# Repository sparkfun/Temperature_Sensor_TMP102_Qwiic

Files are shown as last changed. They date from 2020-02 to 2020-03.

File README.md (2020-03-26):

SparkFun Digital Temperature Sensor - TMP102 (Qwiic)
============================================

[SparkFun Digital Temperature Sensor - TMP102 (Qwiic)  
*SparkFun Digital Temperature Sensor - TMP102 (Qwiic) (SEN-16304)*](https://www.sparkfun.com/products/16304)

Qwiic enabled breakout board for TMP102 digital temperature sensor [The datasheet can be found here.](https://www.sparkfun.com/datasheets/Sensors/Temperature/tmp102.pdf)

Repository Contents
-------------------

* **/Documentation** - Datasheet for the TMP102 (.pdf)
* **/Hardware** - All Eagle design files (.brd and .sch)
* **/Production** - Production panel files

Documentation
--------------
* **[Library](https://github.com/sparkfun/SparkFun_TMP102_Arduino_Library)** - Arduino library for the SparkFun Digital Temperature Sensor - TMP102 (Qwiic).
* **[Hookup Guide](https://learn.sparkfun.com/tutorials/sparkfun-qwiic-digital-temperature-sensor---tmp102-hookup-guide)** - Basic hookup guide for the SparkFun Digital Temperature Sensor - TMP102 (Qwiic).
  
License Information
-------------------
The hardware is released under [Creative Commons Share-alike 3.0](http://creativecommons.org/licenses/by-sa/3.0/).  
All other code is open source so please feel free to do anything you want with it; you buy me a beer if you use this and we meet someday ([Beerware license](http://en.wikipedia.org/wiki/Beerware)).

Design by Kade Alexander Jensen - updated by Alex Wende

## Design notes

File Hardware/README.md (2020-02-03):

SparkFun Temperature Sensor TMP102 (Qwiic) Design Files
=====================================

The .sch and .brd files hare are Eagle CAD schematic and PCB design files from SparkFun Electronics.
A freeware version of Eagle can be found [here](http://www.cadsoftusa.com/download-eagle/freeware/).

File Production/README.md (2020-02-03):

SparkFun Temperature Sensor TMP102(Qwiic) Production Files
=========================================

These are the production files SparkFun uses for printing PCBs.

License Information
-------------------
This product is open source! 

The hardware is released under [Creative Commons ShareAlike 4.0 International](https://creativecommons.org/licenses/by-sa/4.0/).

Please use, reuse, and modify these files as you see fit. Please maintain attribution to SparkFun Electronics and release anything derivative under the same license.

Distributed as-is; no warranty is given.

- Your friends at SparkFun.

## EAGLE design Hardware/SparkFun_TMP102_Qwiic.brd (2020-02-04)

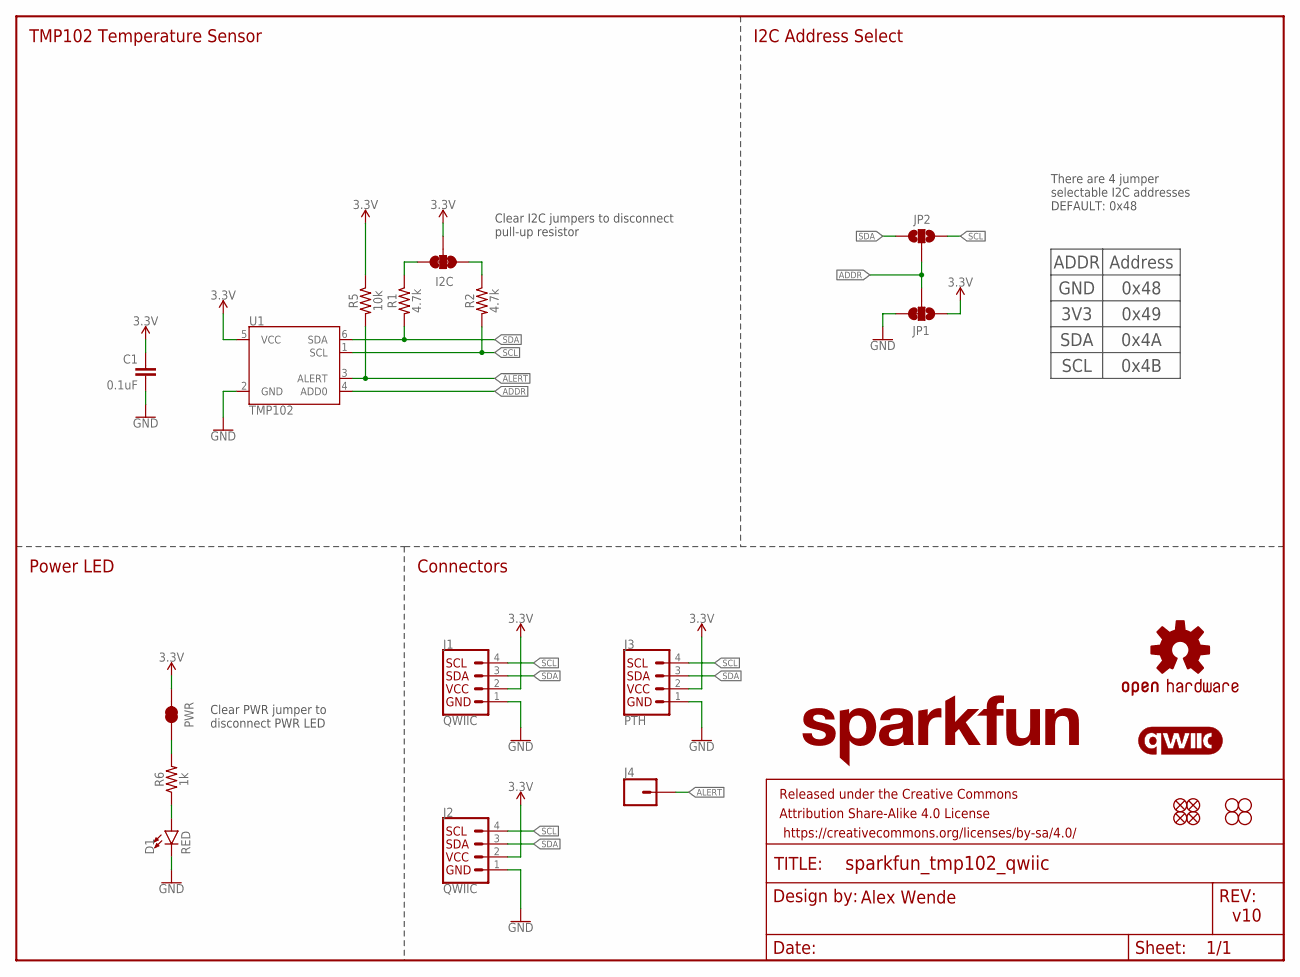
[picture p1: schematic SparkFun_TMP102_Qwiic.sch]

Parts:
C1: 0.1uF; 0603
D1: RED; LED-0603
FD1, FD2, FD3, FD4: FIDUCIALUFIDUCIAL; FIDUCIAL-MICRO
FRAME1: FRAME-LETTER; CREATIVE_COMMONS
H1, H2, H3, H4: STAND-OFF
J1, J2: QWIIC; JST04_1MM_RA
J3: PTH; 1X04_NO_SILK
J4: CONN_01PTH_NO_SILK_YES_STOP; 1X01_NO_SILK
JP1: JUMPER-SMT_3_1-NC_TRACE_NO-SILK; SMT-JUMPER_3_1-NC_TRACE_NO-SILK
JP2: JUMPER-SMT_3_NO_NO-SILK; SMT-JUMPER_3_NO_NO-SILK
JP3: I2C; SMT-JUMPER_3_2-NC_TRACE_SILK
JP4: PWR; SMT-JUMPER_2_NC_TRACE_SILK
LOGO1: SFE_LOGO_NAME.1_INCH; SFE_LOGO_NAME_.1
LOGO2: QWIIC_LOGO_5MM; QWIIC_5MM
LOGO3: OSHW-LOGOS; OSHW-LOGO-S
R1, R2: 4.7k; 0603
R5: 10k; 0603
R6: 1k; 0603
U1: TMP102; SOT563

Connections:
3.3V: C1.1, J1.2, J2.2, J3.2, JP1.1, JP3.2, JP4.2, R5.1, U1.5 (VCC)
!ALERT: J4.1, R5.2, U1.3 (ALERT)
ADDR: JP1.2, JP2.2, U1.4 (ADD0)
GND: C1.2, D1.C, J1.1, J2.1, J3.1, JP1.3, U1.2 (GND)
unnamed: JP3.3, R1.1
unnamed: JP3.1, R2.1
unnamed: D1.A, R6.1
unnamed: JP4.1, R6.2
SCL: J1.4, J2.4, J3.4, JP2.1, R2.2, U1.1 (SCL)
SDA: J1.3, J2.3, J3.3, JP2.3, R1.2, U1.6 (SDA)

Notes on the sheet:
v10
Address
0x48
0x49
0x4A
0x4B
GND
3V3
SDA
SCL
ADDR
I2C Address Select
TMP102 Temperature Sensor
Connectors
There are 4 jumper selectable I2C addresses DEFAULT: 0x48
Clear I2C jumpers to disconnect pull-up resistor
Clear PWR jumper to disconnect PWR LED
Power LED
Alex Wende

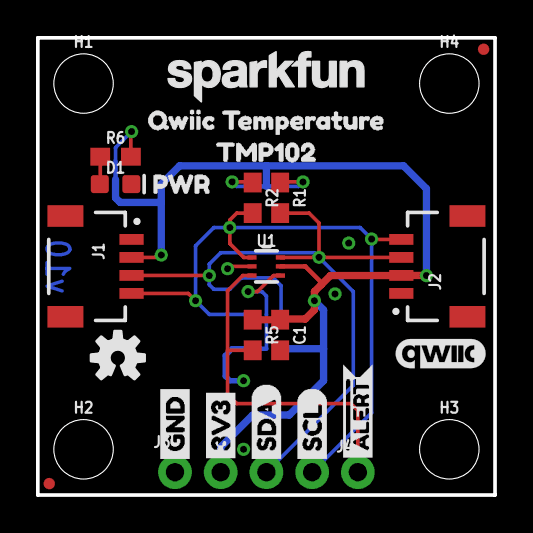
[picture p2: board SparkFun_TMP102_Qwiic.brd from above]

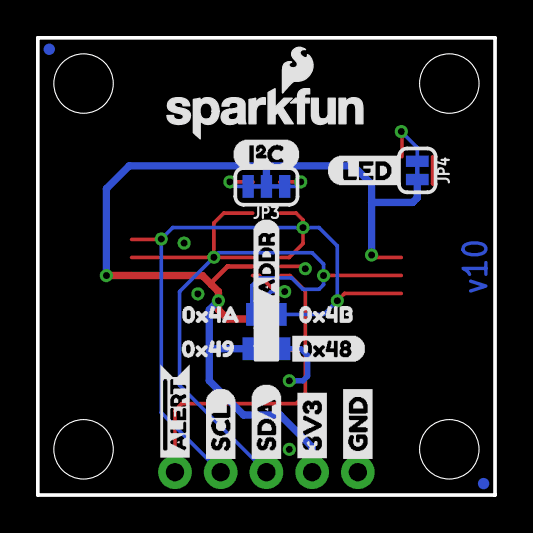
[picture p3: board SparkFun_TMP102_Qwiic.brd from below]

Board: 2 copper layers, 25.4 x 25.4 mm, 48 parts (19 on the bottom side), 10 nets.

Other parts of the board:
U$1, U$10: #ALERT8
U$2, U$9: SCL7
U$3, U$8: SDA6
U$4, U$7: 3V35
U$5, U$6: GND4
U$11: ADDR0
U$12: 0X481
U$13: 0X494
U$14: 0X4A2
U$15: 0X4B3
U$16: I#C0
U$17: LED0
U$18: QWIIC_TEMPERATURE0
U$19: TMP1022
U$20: PWR1
U$21: SFE_LOGO_NAME_FLAME_.1

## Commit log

2020-02-03 intial commit
    [SparkFun_TMP102_Qwiic.brd, SparkFun_TMP102_Qwiic.sch]
2020-02-04 v10 design review changes
    - Added designer name to schematic
    - Mitered I2C pull-up trances going to via
    [SparkFun_TMP102_Qwiic.brd, SparkFun_TMP102_Qwiic.sch]

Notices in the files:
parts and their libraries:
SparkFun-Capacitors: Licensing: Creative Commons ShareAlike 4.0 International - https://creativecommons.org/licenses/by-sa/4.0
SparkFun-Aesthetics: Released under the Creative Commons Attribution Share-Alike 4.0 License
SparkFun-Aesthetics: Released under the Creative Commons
